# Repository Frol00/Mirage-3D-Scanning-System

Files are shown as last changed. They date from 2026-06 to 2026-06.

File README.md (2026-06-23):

# Mirage 3D Scanning System

**Mirage 3D Scanning System** is an open-source RGB-D 3D scanning platform based on Raspberry Pi CM5, Intel RealSense D415, and a custom Mirage V1.1 expansion board.

The system is designed for RGB-D data acquisition, wireless or USB-based data transfer, and 3D reconstruction using a modified InfiniTAM-based MirageApp pipeline.

Repository: https://github.com/Frol00/Mirage-3D-Scanning-System

## Architecture

The system has a distributed architecture and consists of two main nodes:

### Data Acquisition Node
Built on a Raspberry Pi CM5, a Mirage V1.1 expansion board and an Intel RealSense D415 RGB-D camera. Used to connect the camera, launch the local interface, display the system status, control operating modes and transmit the RGB-D stream to a PC. Features physical control buttons to start, stop or reset the scanning process. Designed to operate on battery power.

### Computing Node
Implemented on a PC. Runs MirageApp, a modified program based on InfiniTAM, which receives RGB-D data, processes the depth map, tracks the camera position, integrates frames into a TSDF representation and constructs a polygonal 3D model. The result can be saved in OBJ format.

## Operating Modes

- **Network mode** — the Intel RealSense D415 is connected to the data acquisition node and the RGB-D stream is transmitted to the PC via Wi-Fi.
- **USB mode** — the Intel RealSense D415 is connected directly to the PC via USB.

## Repository Structure

```
hardware/...      — schematics, PCB files and enclosure models
software/...      — software for the data acquisition node and data processing node
experiments/...   — measurements, test models and experimental results
```

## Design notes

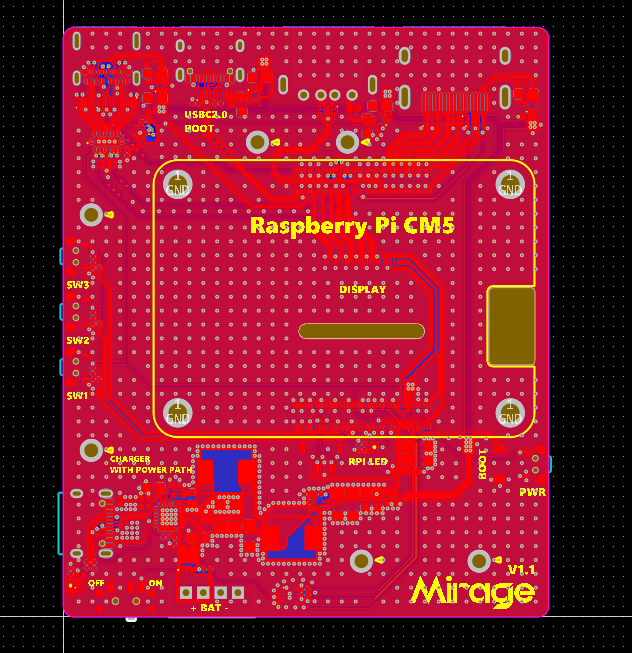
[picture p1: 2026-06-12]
hardware/pcb/PCB_TOP.png

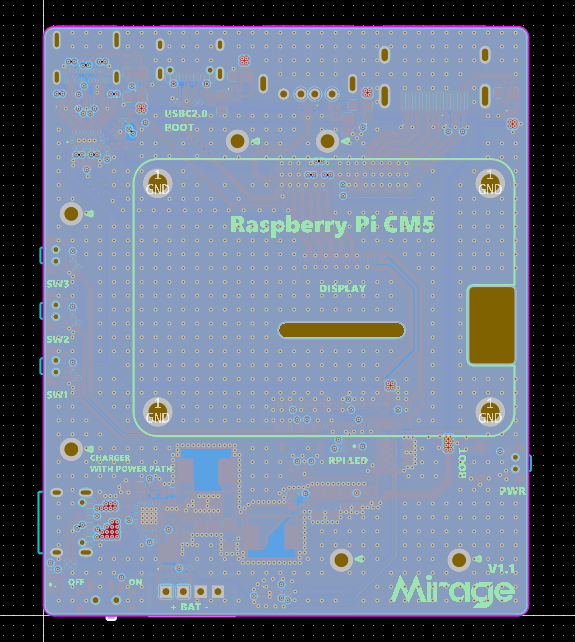
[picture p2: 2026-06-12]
hardware/pcb/PCB_INNER2.png

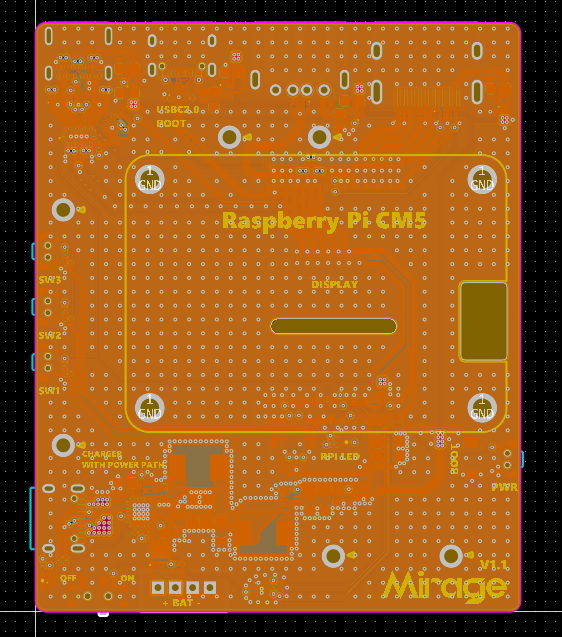
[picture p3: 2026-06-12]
hardware/pcb/PCB_INNER1.png

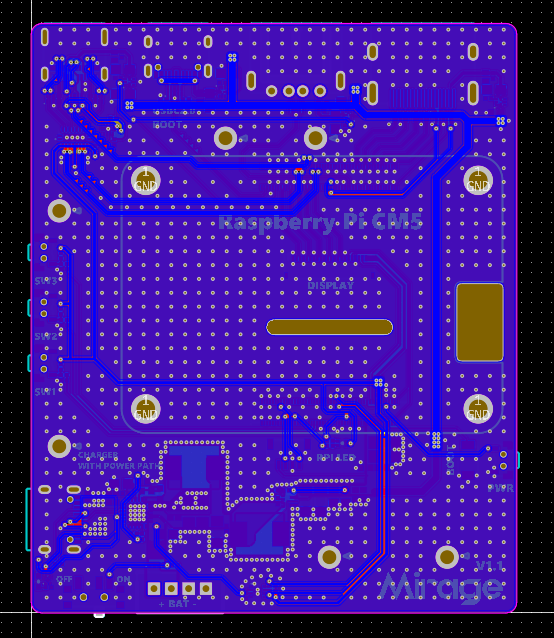
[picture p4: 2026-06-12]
hardware/pcb/PCB_BOTTOM.png

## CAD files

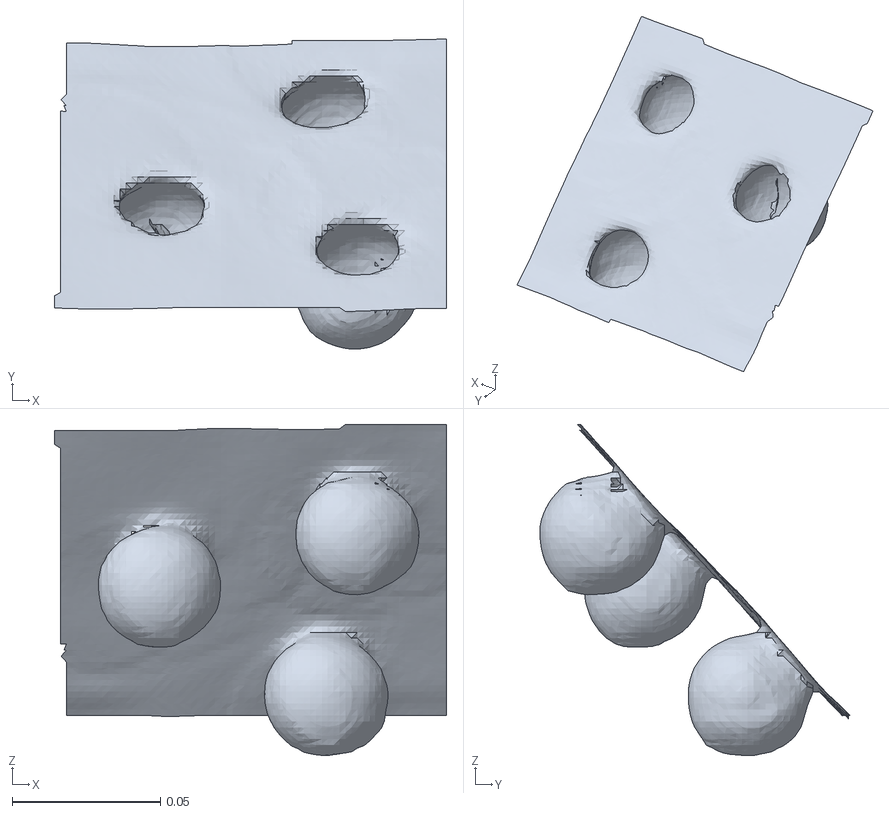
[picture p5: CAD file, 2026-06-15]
experiments/models/Mirage_ball_WIFI.obj
0.132 x 0.104 x 0.112

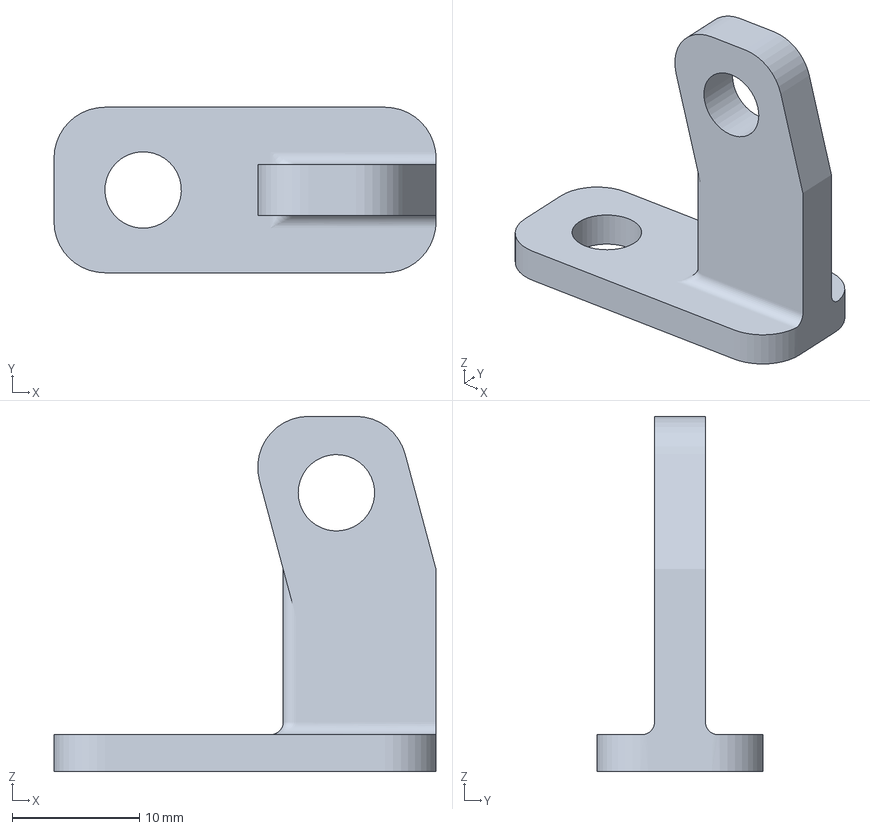
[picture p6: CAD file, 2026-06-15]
hardware/enclosure/CamHolder_TOP.3mf
30.0 x 13.0 x 27.9 mm

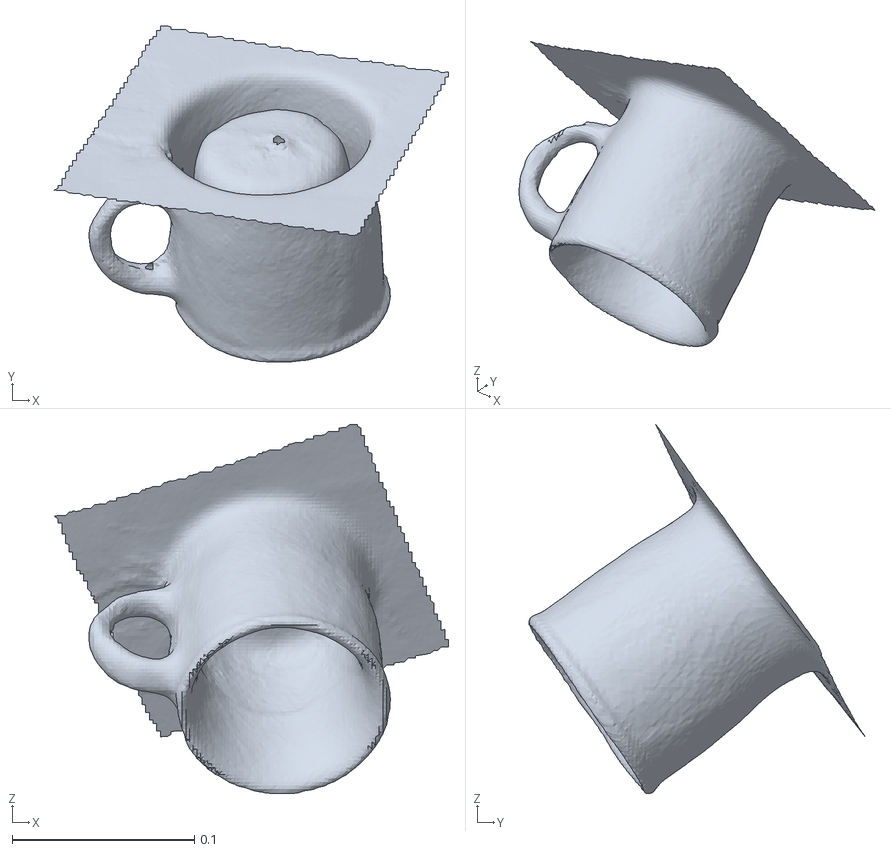
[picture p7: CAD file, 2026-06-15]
experiments/models/Mirage_cup_WIFI.obj
0.216 x 0.184 x 0.202

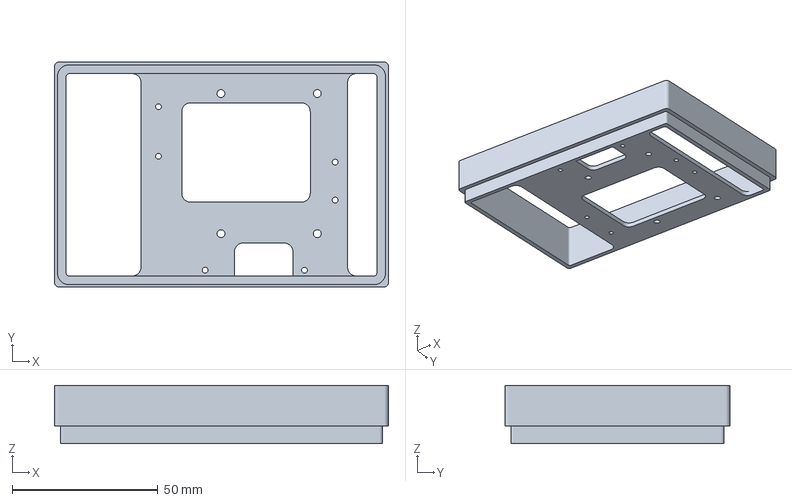
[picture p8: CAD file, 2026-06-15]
hardware/enclosure/BOX_TOP.3mf
114.4 x 77.1 x 20.0 mm

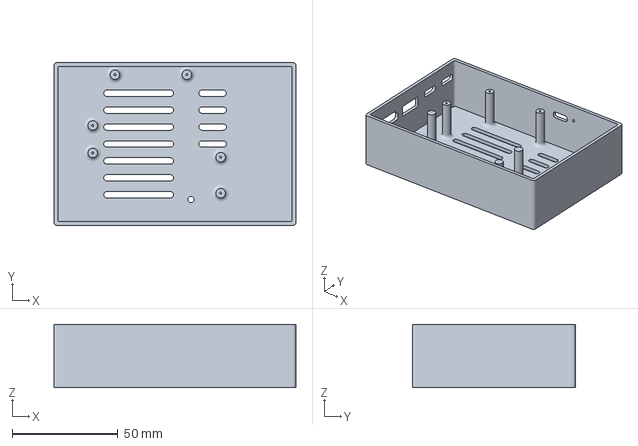
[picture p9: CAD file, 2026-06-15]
hardware/enclosure/BOX_BOTTOM.3mf
114.4 x 77.1 x 30.0 mm

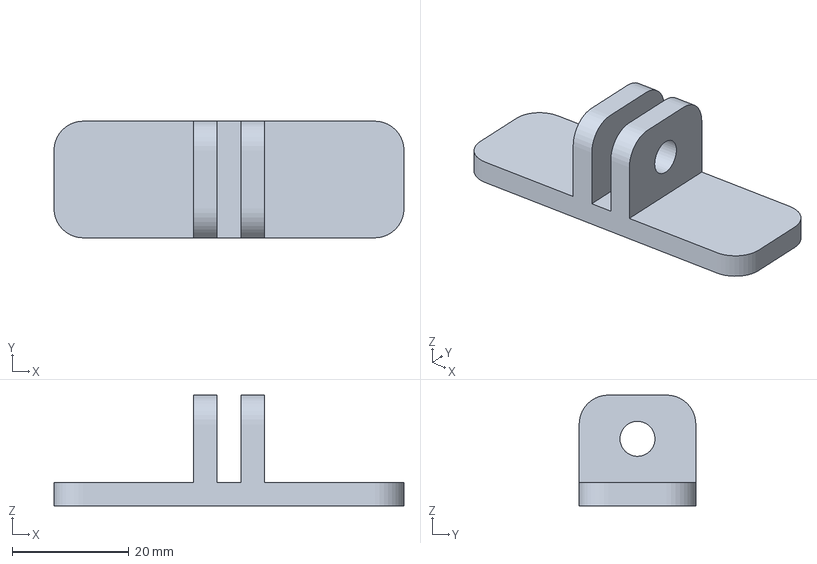
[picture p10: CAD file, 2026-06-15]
hardware/enclosure/CamHolder_BOTTOM.3mf
60.0 x 20.0 x 19.0 mm

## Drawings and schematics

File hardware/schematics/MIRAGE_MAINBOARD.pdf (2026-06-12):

# Raspberry Pi CM5 Pinout

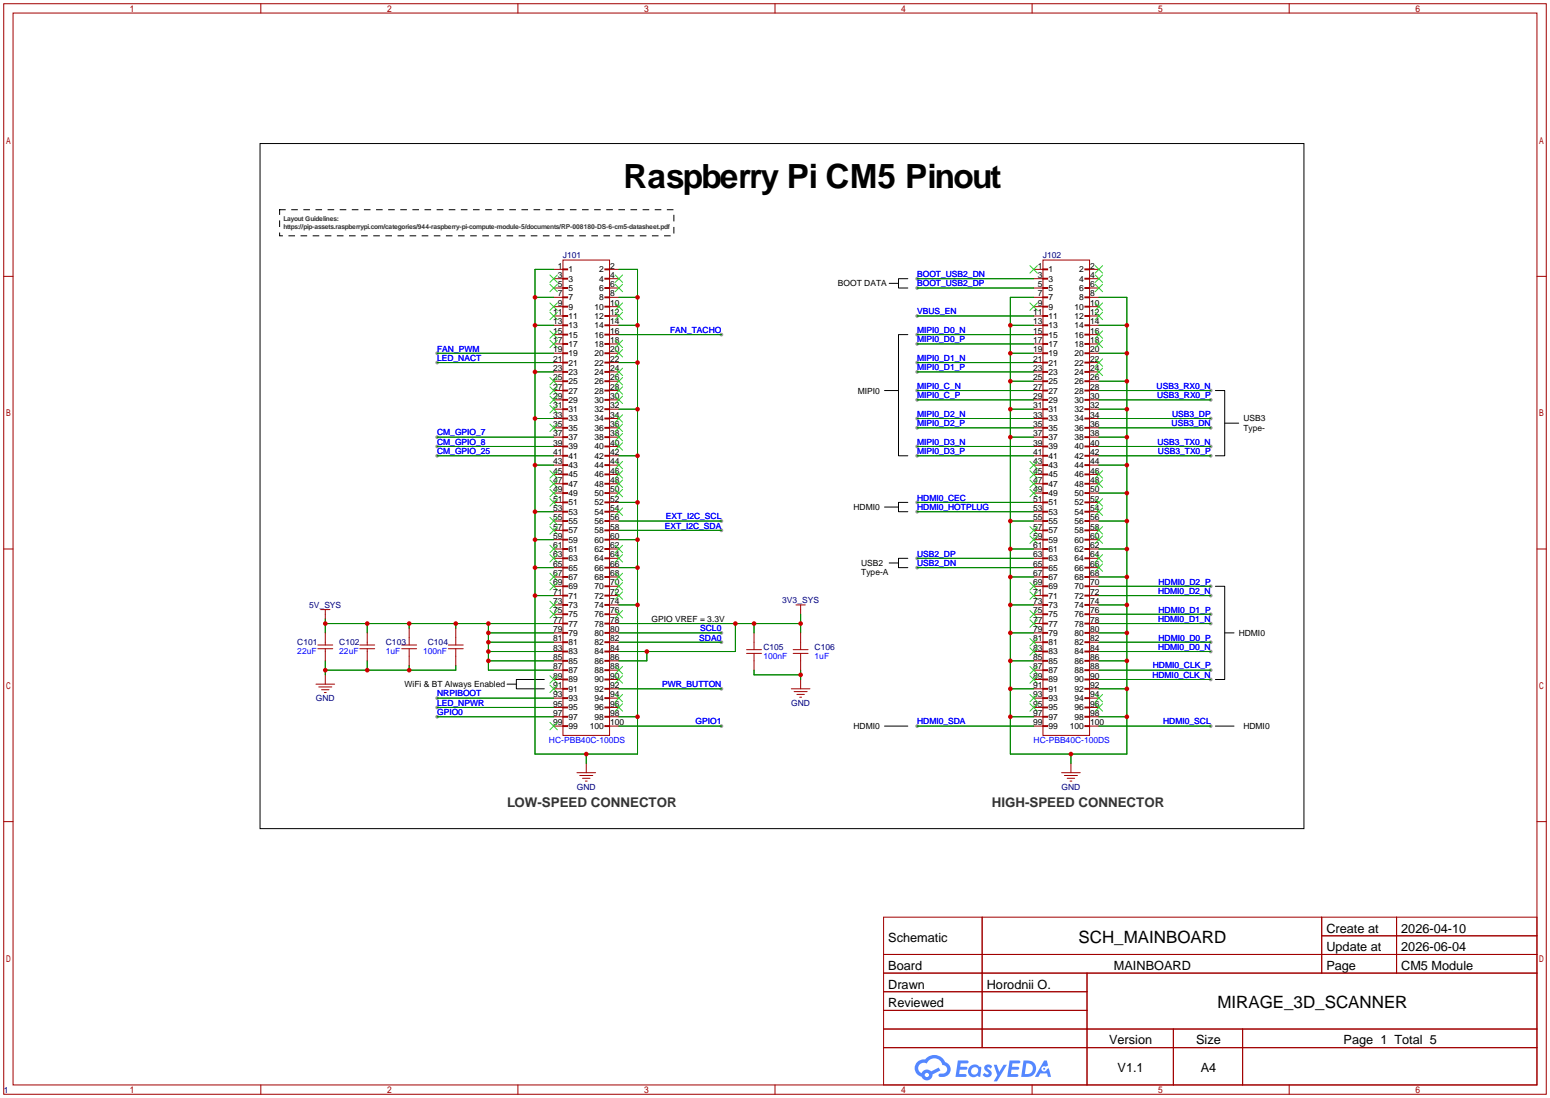
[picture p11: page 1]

Layout Guidelines:
https://pip-assets.raspberrypi.com/categories/944-raspberry-pi-compute-module-5/documents/RP-008180-DS-6-cm5-datasheet.pdf

Schematic | SCH_MAINBOARD | Create at | 2026-04-10

Update at | 2026-06-04

Board | MAINBOARD | Page | CM5 Module
Drawn | Horodnii O. | MIRAGE_3D_SCANNER
Reviewed

Version | Size | Page 1 Total 5
V1.1 | A4

# BATTERY CHARGER WITH POWER PATH

# DC-DC BOOST

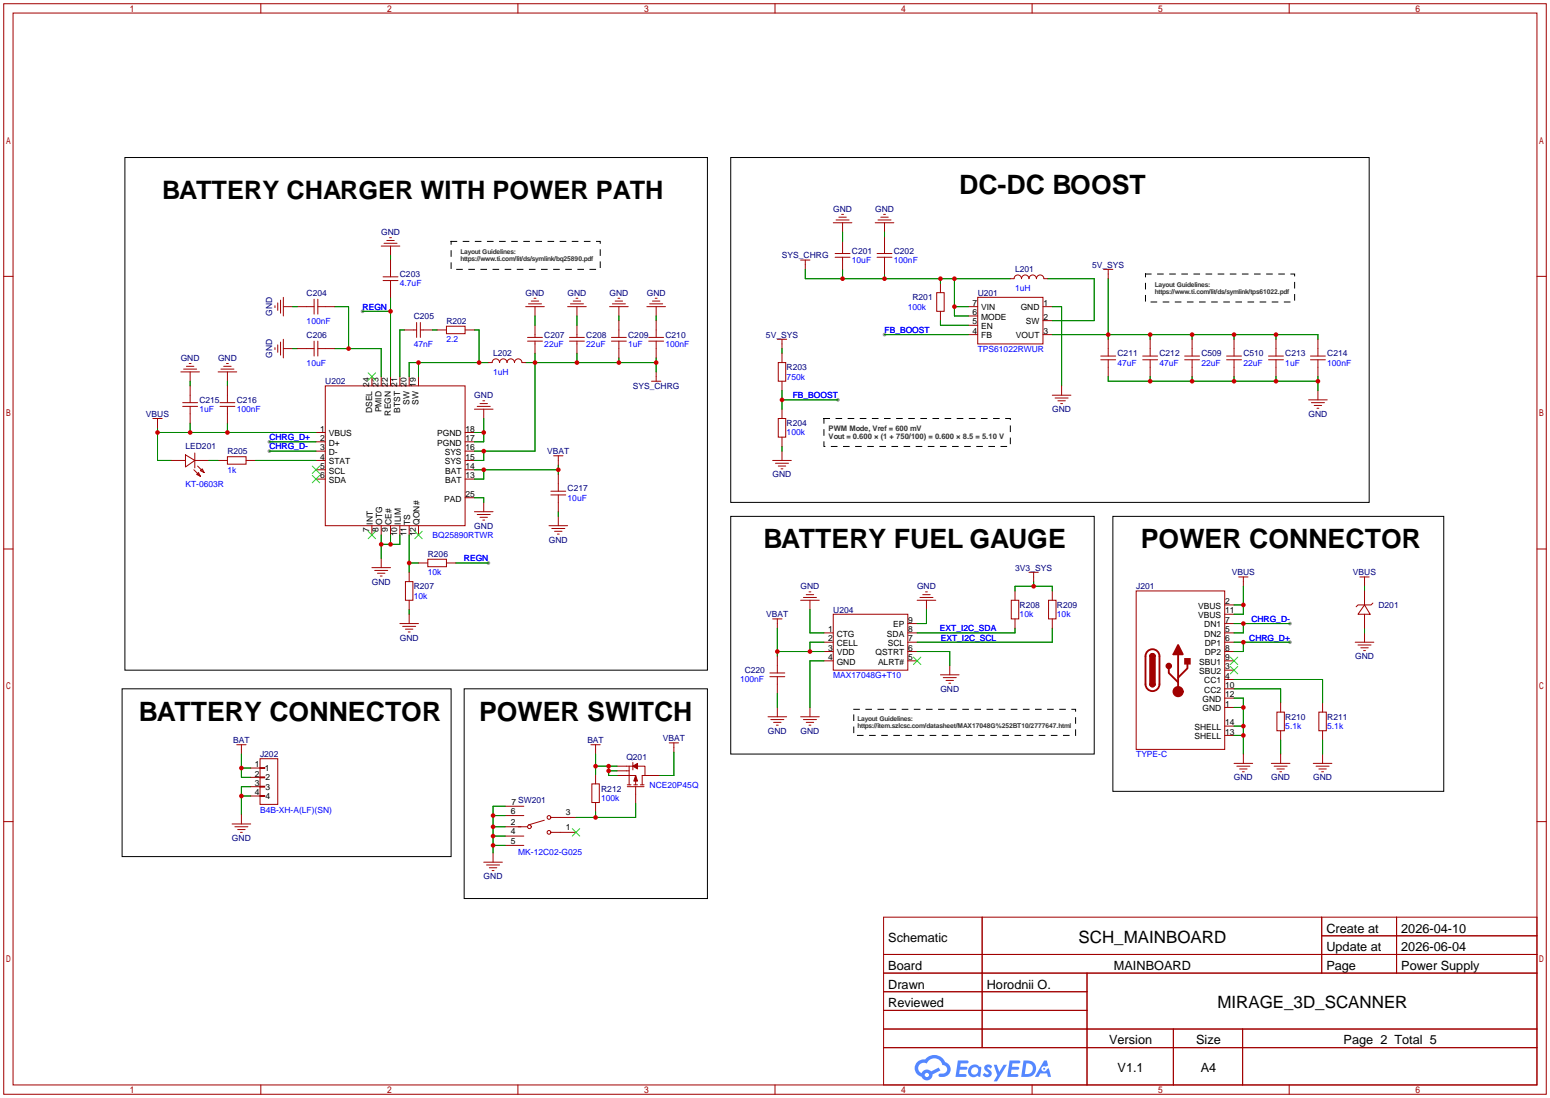
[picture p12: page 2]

Layout Guidelines:
https://www.ti.com/lit/ds/symlink/bq25890.pdf

https://www.ti.com/lit/ds/symlink/tps61022.pdf

BAT 13 BAT 14 SYS 15 SYS 16 PGND 17 PGND 18

PWM Mode, Vref = 600 mV
Vout = 0.600 × (1 + 750/100) = 0.600 × 8.5 = 5.10 V

https://item.szlcsc.com/datasheet/MAX17048G%252BT10/2777647.html

Schematic | SCH_MAINBOARD | Create at | 2026-04-10

Update at | 2026-06-04

Board | MAINBOARD | Page | Power Supply
Drawn | Horodnii O. | MIRAGE_3D_SCANNER
Reviewed

# USB 2.0 Type-A (DEFAULT)

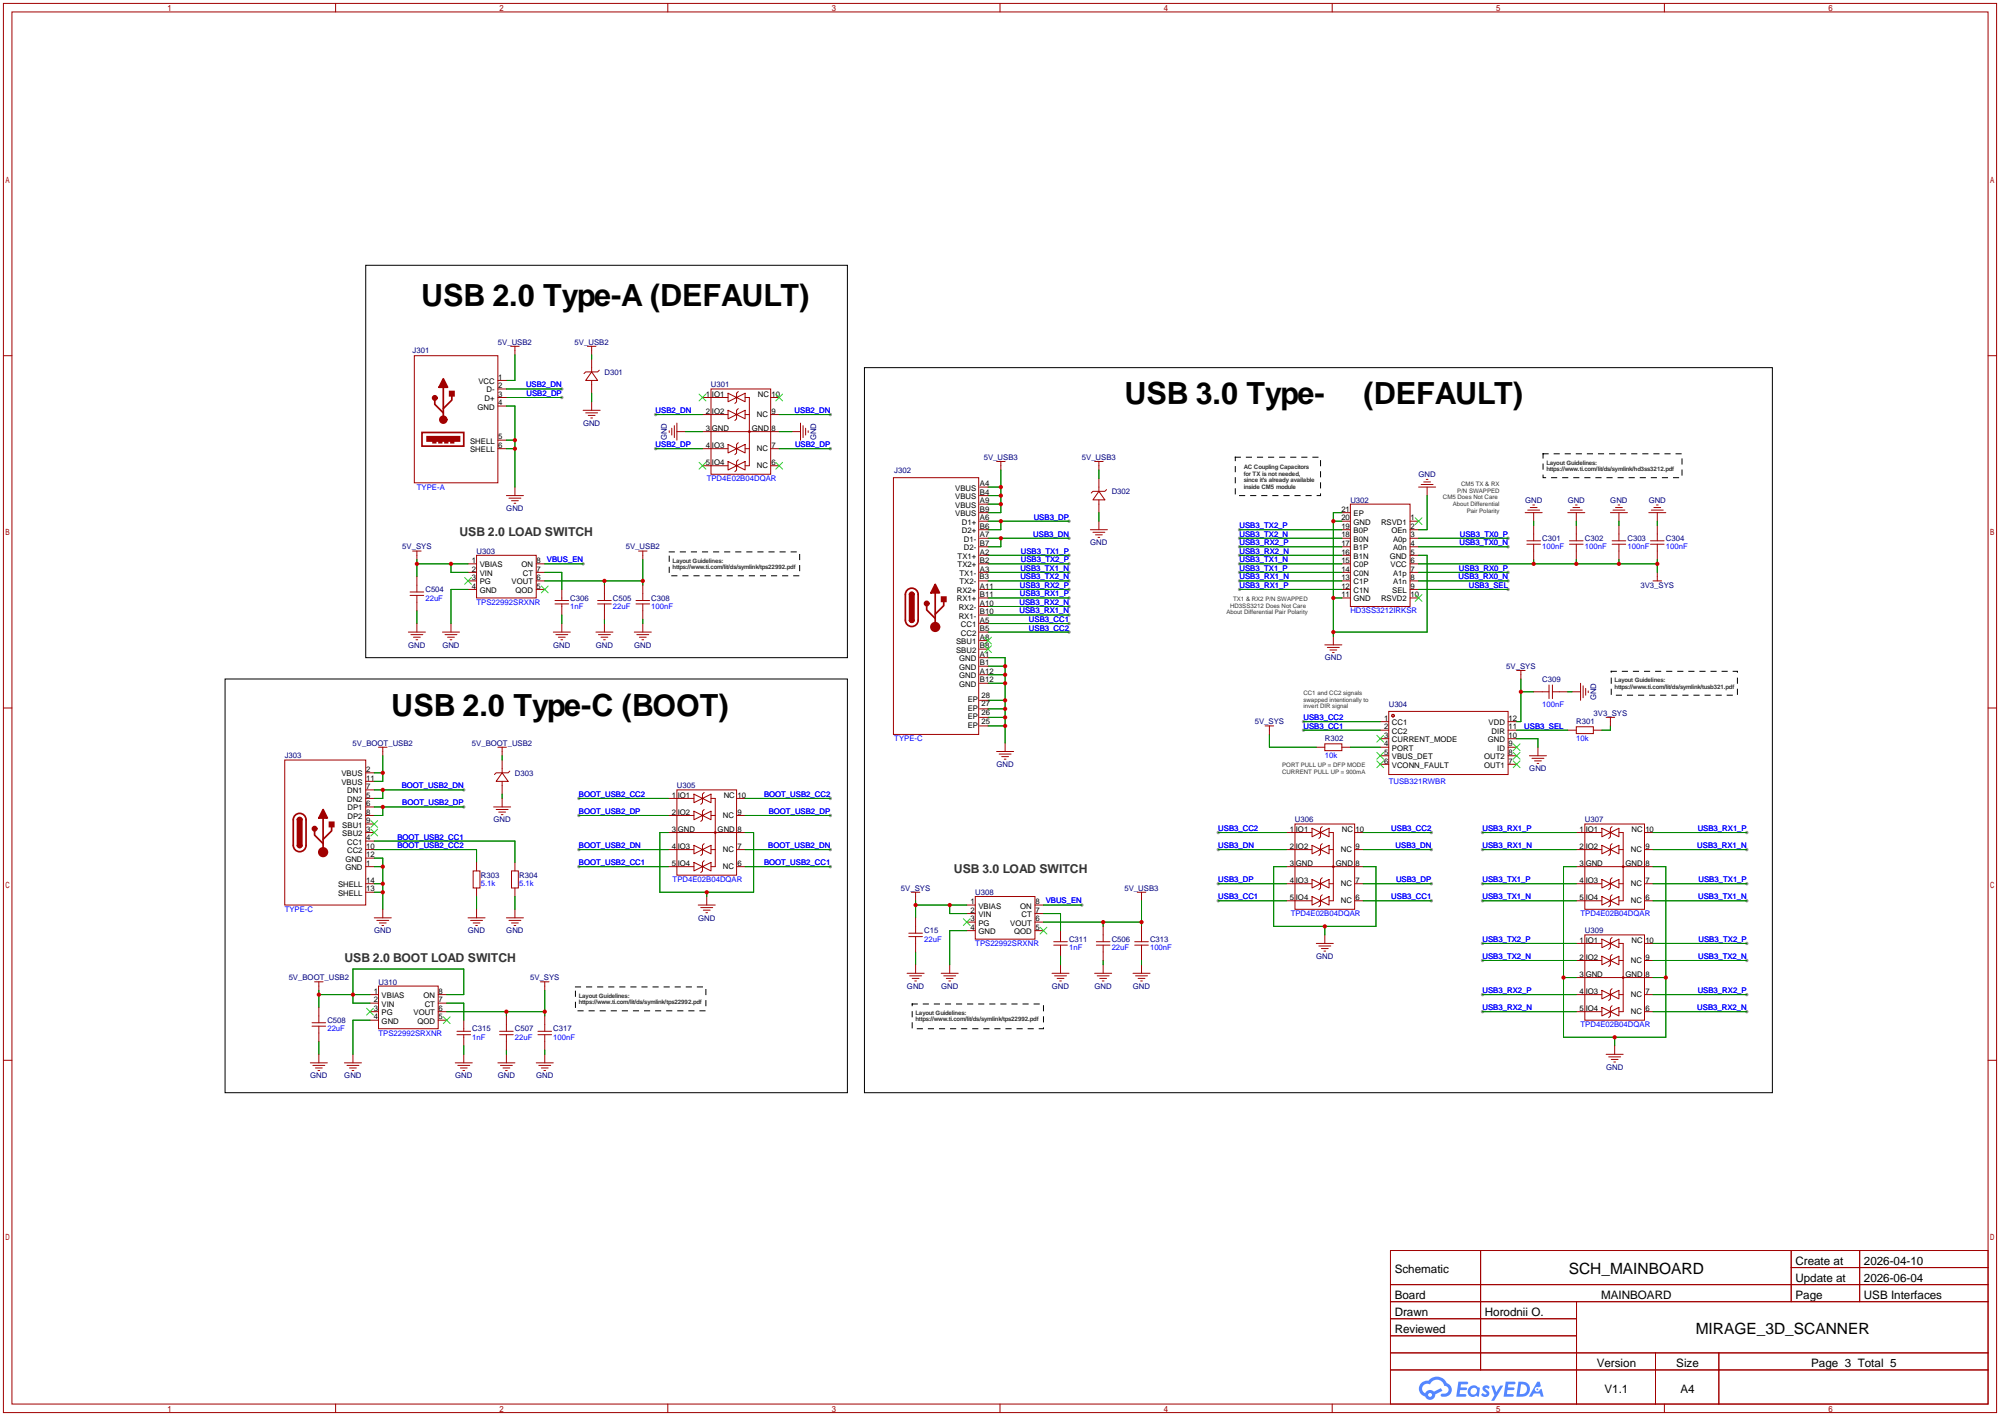
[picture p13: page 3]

Layout Guidelines:
https://www.ti.com/lit/ds/symlink/hd3ss3212.pdf

AC Coupling Capacitors
for TX is not needed,
since it's already available
inside CM5 module

https://www.ti.com/lit/ds/symlink/tps22992.pdf

https://www.ti.com/lit/ds/symlink/tusb321.pdf

PORT PULL UP = DFP MODE
CURRENT PULL UP = 900mA

GND
USB 2.0 BOOT LOAD SWITCH

Schematic | SCH_MAINBOARD | Create at | 2026-04-10

Update at | 2026-06-04

Board | MAINBOARD | Page | USB Interfaces
Drawn | Horodnii O. | MIRAGE_3D_SCANNER
Reviewed

# HDMI-A

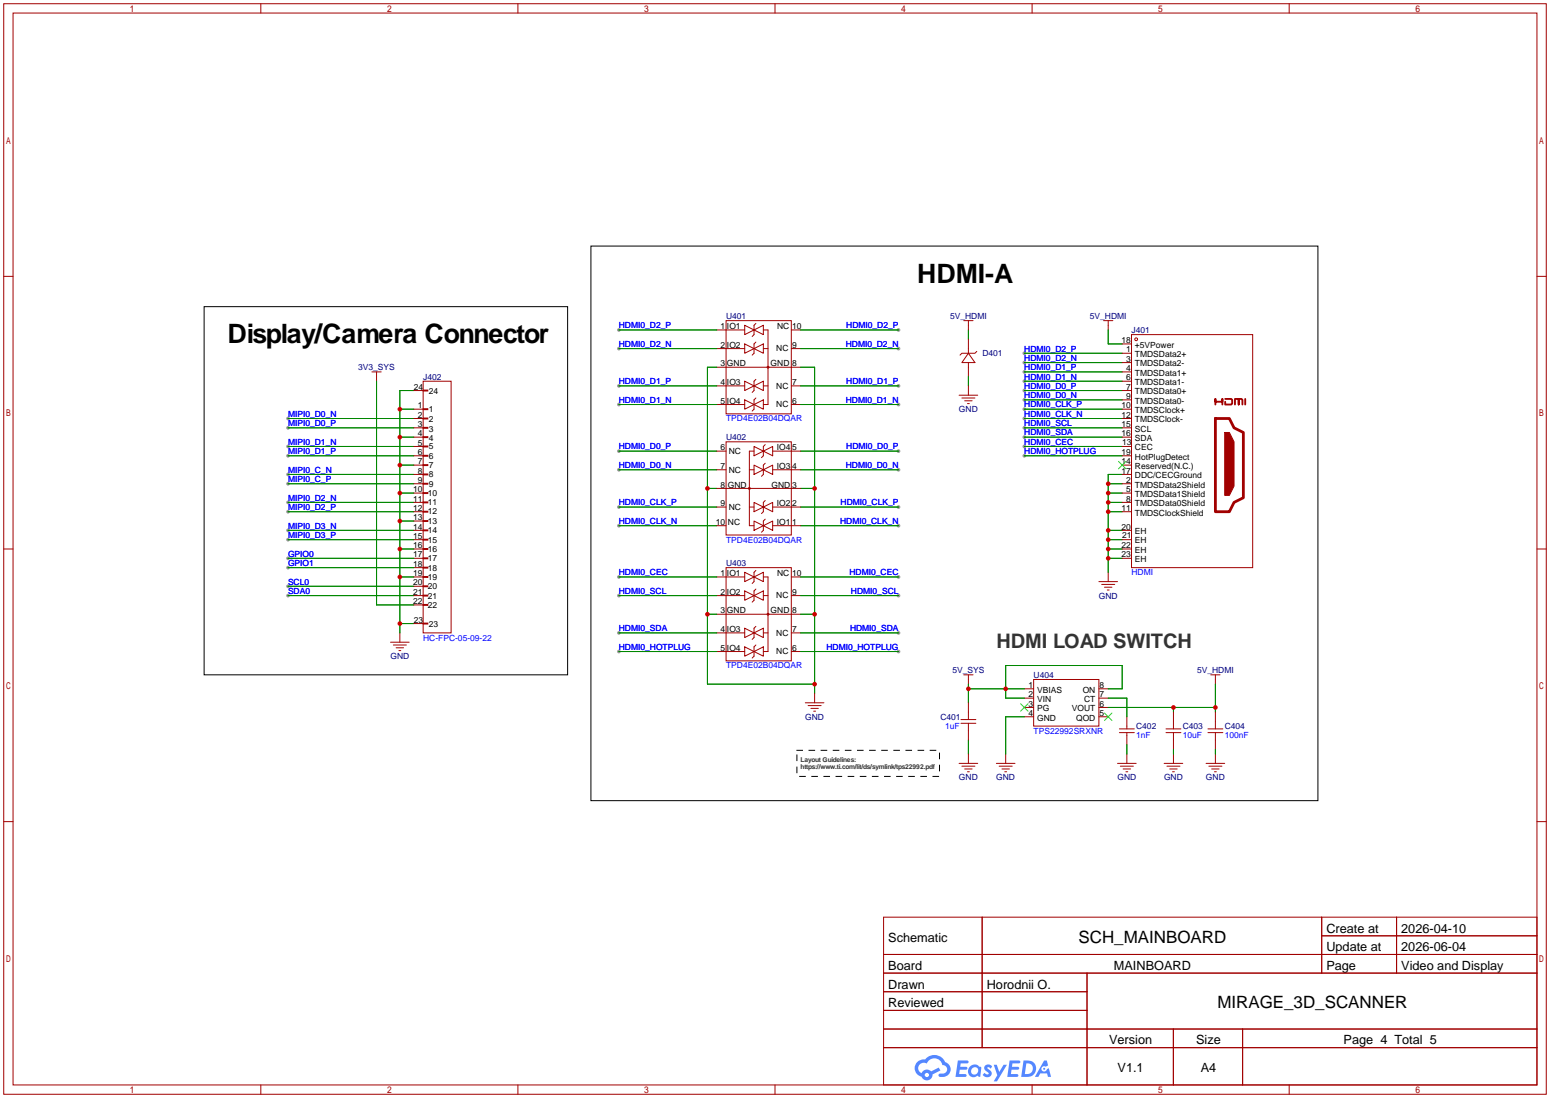
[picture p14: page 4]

Layout Guidelines:
https://www.ti.com/lit/ds/symlink/tps22992.pdf

Schematic | SCH_MAINBOARD | Create at | 2026-04-10

Update at | 2026-06-04

Board | MAINBOARD | Page | Video and Display
Drawn | Horodnii O. | MIRAGE_3D_SCANNER
Reviewed

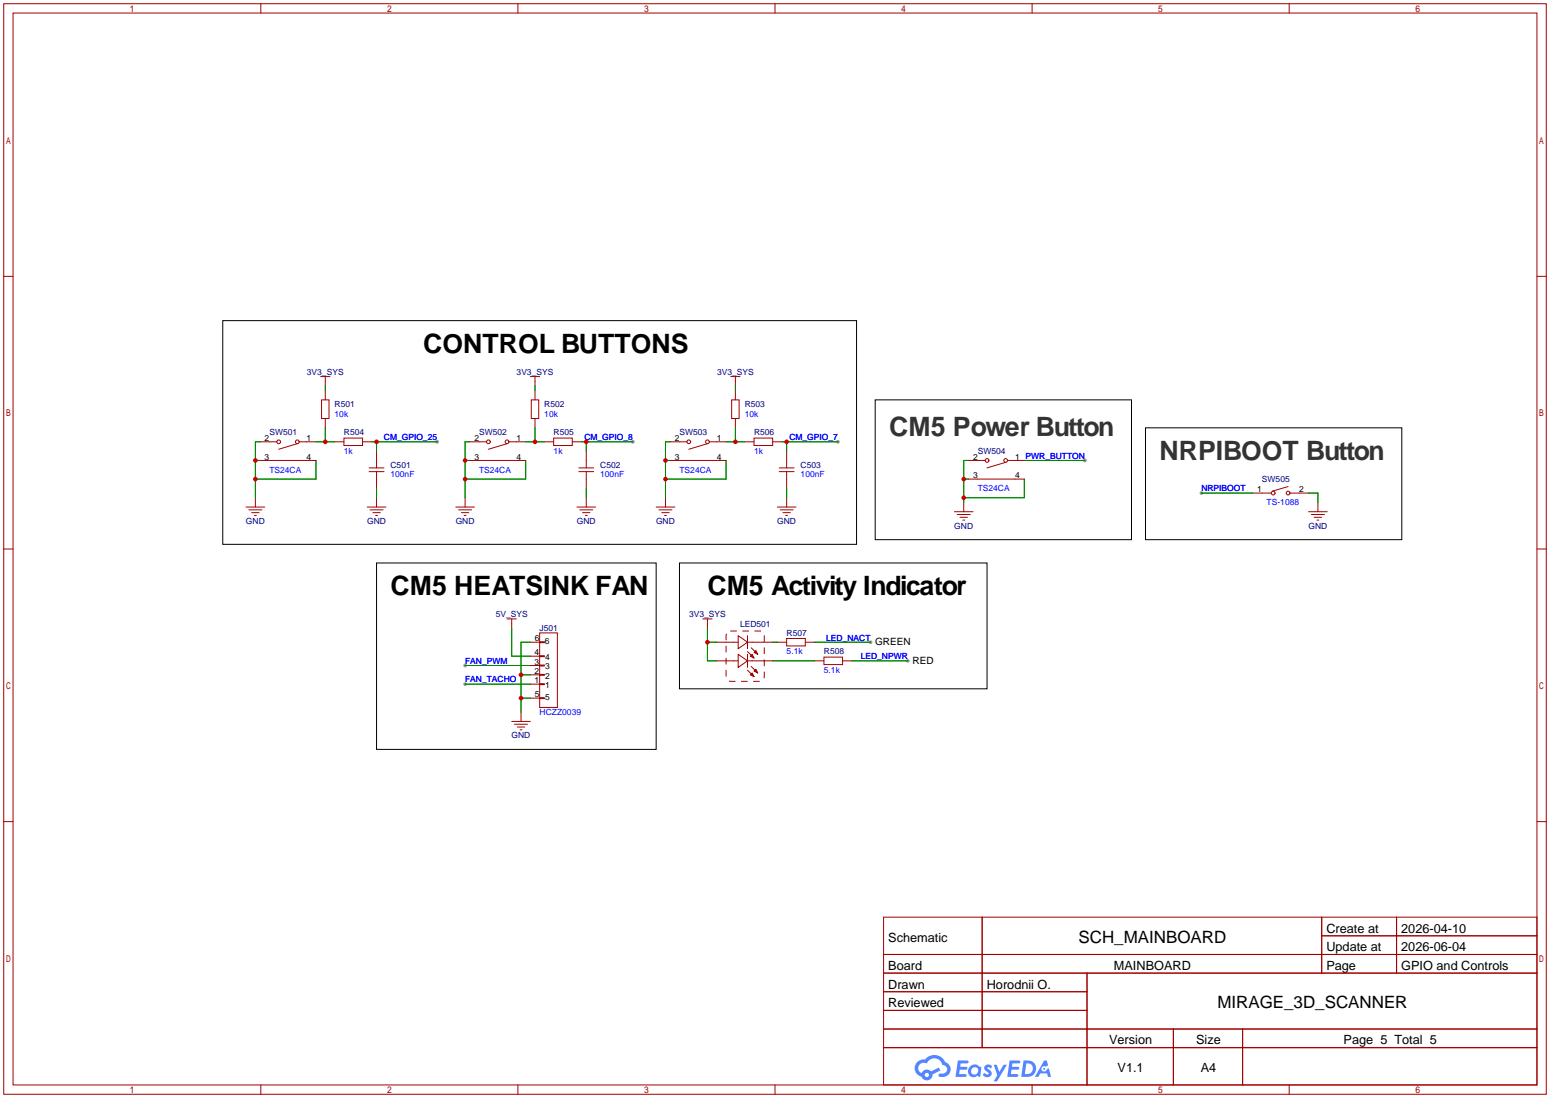
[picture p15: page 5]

Schematic | SCH_MAINBOARD | Create at | 2026-04-10

Update at | 2026-06-04

Board | MAINBOARD | Page | GPIO and Controls
Drawn | Horodnii O. | MIRAGE_3D_SCANNER
Reviewed

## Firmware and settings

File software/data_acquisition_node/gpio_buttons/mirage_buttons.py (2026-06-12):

#!/usr/bin/env python3
import argparse
import json
import os
import signal
import socket
import sys
import threading
import time
import urllib.error
import urllib.parse
import urllib.request
from http.server import ThreadingHTTPServer, BaseHTTPRequestHandler
from pathlib import Path

try:
    from gpiozero import Button
    GPIO_AVAILABLE = True
except Exception as exc:
    Button = None
    GPIO_AVAILABLE = False
    GPIO_IMPORT_ERROR = exc


SCRIPT_DIR = Path(__file__).resolve().parent
DEFAULT_CONFIG = SCRIPT_DIR / "mirage_buttons_config.json"
COMMANDS = {"start", "stop", "reset"}


def log(message):
    print(time.strftime("[%Y-%m-%d %H:%M:%S]"), message, flush=True)


def load_json(path, fallback):
    try:
        return json.loads(Path(path).read_text(encoding="utf-8"))
    except FileNotFoundError:
        return fallback


def write_json(path, data):
    path = Path(path)
    path.parent.mkdir(parents=True, exist_ok=True)
    path.write_text(json.dumps(data, indent=2, ensure_ascii=False), encoding="utf-8")


class ClientState:
    def __init__(self, state_file, default_port, default_protocol):
        self.state_file = Path(state_file)
        self.default_port = int(default_port)
        self.default_protocol = str(default_protocol)
        self.lock = threading.Lock()
        self.client = self._load()

    def _load(self):
        data = load_json(self.state_file, {})
        if not isinstance(data, dict):
            return {}
        return data

    def get(self):
        with self.lock:
            return dict(self.client)

    def clear(self):
        with self.lock:
            self.client = {}
            write_json(self.state_file, self.client)

    def register(self, ip, port=None, protocol=None):
        if not port:
            port = self.default_port
        if not protocol:
            protocol = self.default_protocol

        client = {
            "ip": str(ip),
            "port": int(port),
            "protocol": str(protocol).lower(),
            "registered_at": time.time()
        }

        with self.lock:
            self.client = client
            write_json(self.state_file, self.client)

        return client


class MirageButtons:
    def __init__(self, config):
        self.config = config
        client_cfg = config.get("client", {})
        self.client_state = ClientState(
            config.get("state_file", "/home/frol/mirage_buttons/client_state.json"),
            client_cfg.get("default_port", 5055),
            client_cfg.get("protocol", "http")
        )
        self.httpd = None
        self.buttons = []
        self.stopping = threading.Event()

    def check_token(self, handler):
        expected = str(self.config.get("token", "") or "")
        if not expected:
            return True

        header = handler.headers.get("X-Mirage-Token", "")
        query = urllib.parse.parse_qs(urllib.parse.urlparse(handler.path).query)
        query_token = query.get("token", [""])[0]
        return header == expected or query_token == expected

    def send_command(self, command):
        command = str(command).strip().lower()
        if command not in COMMANDS:
            raise ValueError("Unknown command: " + command)

        client = self.client_state.get()
        if not client.get("ip"):
            log("Button command ignored, no active PC client: " + command)
            return {"ok": False, "error": "No active client", "command": command}

        protocol = client.get("protocol", "http")
        if protocol == "udp":
            return self._send_udp(client, command)
        return self._send_http(client, command)

    def _send_http(self, client, command):
        cfg = self.config.get("client", {})
        template = cfg.get("http_path_template", "/{command}")
        method = str(cfg.get("http_method", "GET")).upper()
        timeout = float(cfg.get("timeout_sec", 1.0))
        path = template.format(command=urllib.parse.quote(command))
        if not path.startswith("/"):
            path = "/" + path

        url = "http://{}:{}{}".format(client["ip"], int(client["port"]), path)
        data = None
        headers = {}

        token = str(self.config.get("token", "") or "")
        if token:
            headers["X-Mirage-Token"] = token

        if method == "POST":
            data = json.dumps({"command": command}).encode("utf-8")
            headers["Content-Type"] = "application/json"

        req = urllib.request.Request(url, data=data, headers=headers, method=method)

        try:
            with urllib.request.urlopen(req, timeout=timeout) as response:
                body = response.read(256).decode("utf-8", errors="replace")
            log("Sent {} to {} by HTTP {}".format(command, client["ip"], response.status))
            return {"ok": True, "command": command, "url": url, "status": response.status, "body": body}
        except urllib.error.URLError as exc:
            log("Failed to send {} to {}: {}".format(command, client["ip"], exc))
            return {"ok": False, "command": command, "url": url, "error": str(exc)}

    def _send_udp(self, client, command):
        cfg = self.config.get("client", {})
        timeout = float(cfg.get("timeout_sec", 1.0))
        encoding = cfg.get("udp_encoding", "utf-8")
        payload = command.encode(encoding)

        with socket.socket(socket.AF_INET, socket.SOCK_DGRAM) as sock:
            sock.settimeout(timeout)
            sock.sendto(payload, (client["ip"], int(client["port"])))

        log("Sent {} to {} by UDP".format(command, client["ip"]))
        return {"ok": True, "command": command}

    def start_http_server(self):
        app = self

        class Handler(BaseHTTPRequestHandler):
            server_version = "MirageButtons/1.0"

            def log_message(self, fmt, *args):
                log("{} {}".format(self.client_address[0], fmt % args))

            def _json(self, data, code=200):
                body = json.dumps(data, ensure_ascii=False).encode("utf-8")
                self.send_response(code)
                self.send_header("Content-Type", "application/json; charset=utf-8")
                self.send_header("Content-Length", str(len(body)))
                self.send_header("Cache-Control", "no-store")
                self.end_headers()
                self.wfile.write(body)

            def _body_json(self):
                length = int(self.headers.get("Content-Length", "0") or "0")
                if length <= 0:
                    return {}
                raw = self.rfile.read(length)
                try:
                    return json.loads(raw.decode("utf-8"))
                except Exception:
                    return {}

            def _require_token(self):
                if app.check_token(self):
                    return True
                self._json({"ok": False, "error": "Forbidden"}, 403)
                return False

            def do_GET(self):
                if not self._require_token():
                    return

                path = urllib.parse.urlparse(self.path).path
                if path == "/status":
                    return self._json({
                        "ok": True,
                        "client": app.client_state.get(),
                        "gpio_available": GPIO_AVAILABLE
                    })

                if path == "/clear":
                    app.client_state.clear()
                    return self._json({"ok": True})

                if path.startswith("/send/"):
                    command = path.rsplit("/", 1)[-1]
                    return self._json(app.send_command(command))

                return self._json({"ok": False, "error": "Not found"}, 404)

            def do_POST(self):
                if not self._require_token():
                    return

                path = urllib.parse.urlparse(self.path).path
                data = self._body_json()

                if path == "/register":
                    client = app.client_state.register(
                        self.client_address[0],
                        data.get("port"),
                        data.get("protocol")
                    )
                    log("Registered active PC client: {}:{} {}".format(
                        client["ip"], client["port"], client["protocol"]))
                    return self._json({"ok": True, "client": client})

                if path == "/clear":
                    app.client_state.clear()
                    return self._json({"ok": True})

                if path.startswith("/send/"):
                    command = path.rsplit("/", 1)[-1]
                    return self._json(app.send_command(command))

                return self._json({"ok": False, "error": "Not found"}, 404)

        host = self.config.get("listen_host", "0.0.0.0")
        port = int(self.config.get("listen_port", 8091))
        self.httpd = ThreadingHTTPServer((host, port), Handler)

        thread = threading.Thread(target=self.httpd.serve_forever, daemon=True)
        thread.start()
        log("Mirage buttons server listening on {}:{}".format(host, port))

    def setup_buttons(self):
        if not GPIO_AVAILABLE:
            log("GPIO unavailable: {}".format(GPIO_IMPORT_ERROR))
            log("HTTP registration/test server will still run.")
            return

        button_cfg = self.config.get("buttons", {})

        self._add_press_button("start", button_cfg.get("start", {}))
        self._add_press_button("stop", button_cfg.get("stop", {}))
        self._add_reset_button(button_cfg.get("reset", {}))

    def _add_press_button(self, command, cfg):
        pin = cfg.get("pin")
        if pin is None:
            log("Button disabled, no pin configured: " + command)
            return

        btn = Button(
            int(pin),
            pull_up=bool(cfg.get("pull_up", True)),
            bounce_time=float(cfg.get("bounce_time", 0.08))
        )
        btn.when_pressed = lambda cmd=command: self.send_command(cmd)
        self.buttons.append(btn)
        log("GPIO button {} on BCM pin {}".format(command, pin))

    def _add_reset_button(self, cfg):
        pin = cfg.get("pin")
        if pin is None:
            log("Reset button disabled, no pin configured.")
            return

        btn = Button(
            int(pin),
            pull_up=bool(cfg.get("pull_up", True)),
            bounce_time=float(cfg.get("bounce_time", 0.08)),
            hold_time=float(cfg.get("hold_time", 1.5)),
            hold_repeat=False
        )
        btn.when_held = lambda: self.send_command("reset")
        self.buttons.append(btn)
        log("GPIO button reset on BCM pin {} hold {} sec".format(pin, btn.hold_time))

    def run(self):
        self.start_http_server()
        self.setup_buttons()

        while not self.stopping.is_set():
            time.sleep(0.25)

    def stop(self):
        self.stopping.set()
        if self.httpd:
            self.httpd.shutdown()


def main():
    parser = argparse.ArgumentParser(description="Mirage GPIO buttons to PC control bridge")
    parser.add_argument("--config", default=str(DEFAULT_CONFIG))
    args = parser.parse_args()

    config = load_json(args.config, {})
    if not config:
        print("Config not found or empty: {}".format(args.config), file=sys.stderr)
        return 2

    app = MirageButtons(config)

    def handle_signal(signum, frame):
        log("Stopping")
        app.stop()

    signal.signal(signal.SIGTERM, handle_signal)
    signal.signal(signal.SIGINT, handle_signal)

    app.run()
    return 0


if __name__ == "__main__":
    raise SystemExit(main())

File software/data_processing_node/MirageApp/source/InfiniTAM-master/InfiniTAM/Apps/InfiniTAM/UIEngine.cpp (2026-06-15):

// Copyright 2014-2017 Oxford University Innovation Limited and the authors of InfiniTAM

#ifdef _WIN32
#ifndef WIN32_LEAN_AND_MEAN
#define WIN32_LEAN_AND_MEAN
#endif
#ifndef NOMINMAX
#define NOMINMAX
#endif
#include <winsock2.h>
#include <ws2tcpip.h>
#ifdef _MSC_VER
#pragma comment(lib, "Ws2_32.lib")
#endif
#endif

#include "UIEngine.h"
#include "ImGuiGlutBridge.h"

#include <algorithm>
#include <cctype>
#include <chrono>
#include <cmath>
#include <iostream>
#include <string.h>
#include <ctime>
#include <sstream>
#include <stdexcept>
#include <thread>

#ifdef __APPLE__
#include <GLUT/glut.h>
#else
#include <GL/glut.h>
#endif

#include <imgui.h>
#include <imgui_impl_opengl3.h>

#ifdef FREEGLUT
#include <GL/freeglut.h>
#else
#if (!defined USING_CMAKE) && (defined _MSC_VER)
#pragma comment(lib, "glut64")
#endif
#endif

#include "../../ITMLib/ITMLibDefines.h"
#include "../../ITMLib/Core/ITMBasicEngine.h"
#include "../../ITMLib/Core/ITMBasicSurfelEngine.h"
#include "../../ITMLib/Core/ITMMultiEngine.h"

#include "../../ORUtils/FileUtils.h"
#include "../../InputSource/FFMPEGWriter.h"
#include "../../InputSource/RealSense2Engine.h"
#include "../../InputSource/RealSense2NetworkEngine.h"

#ifdef COMPILE_WITH_RealSense2
#include <librealsense2/rs.hpp>
#endif

using namespace InfiniTAM::Engine;
using namespace InputSource;
using namespace ITMLib;

UIEngine* UIEngine::instance;

static void safe_glutBitmapString(void *font, const char *str)
{
	size_t len = strlen(str);
	for (size_t x = 0; x < len; ++x) {
		glutBitmapCharacter(font, str[x]);
	}
}

namespace
{
	const char *kResolutionNames[] = { "1280 x 720", "848 x 480", "640 x 480" };
	const Vector2i kResolutions[] = { Vector2i(1280, 720), Vector2i(848, 480), Vector2i(640, 480) };
	const char *kPresetNames[] = { "Default", "High Density", "High Accuracy" };
	const char *kFrameStrideNames[] = { "Every frame", "Every 2nd frame", "Every 3rd frame", "Every 4th frame" };
	const int kFrameStrides[] = { 1, 2, 3, 4 };
	const char *kScanAreaNames[] = { "10 x 10 cm", "25 x 25 cm", "50 x 50 cm", "100 x 100 cm" };
	const float kScanAreaSizesM[] = { 0.10f, 0.25f, 0.50f, 1.00f };
	const char *kMeshDetailNames[] = { "Balanced (5 mm)", "Fine (3 mm)", "Ultra (2 mm)" };
	const float kMeshVoxelSizesM[] = { 0.005f, 0.003f, 0.002f };
	const char *kDepthOnlyTrackerConfig =
		"type=extended,levels=rrbb,useDepth=1,minstep=1e-4,"
		"outlierSpaceC=0.1,outlierSpaceF=0.004,"
		"numiterC=20,numiterF=50,tukeyCutOff=8,"
		"framesToSkip=20,framesToWeight=50,failureDec=20.0";
	const char *kColourDepthTrackerConfig =
		"type=extended,levels=bbb,useDepth=1,useColour=1,"
		"colourWeight=0.2,minstep=1e-4,"
		"outlierColourC=0.175,outlierColourF=0.005,"
		"outlierSpaceC=0.1,outlierSpaceF=0.004,"
		"numiterC=8,numiterF=12,tukeyCutOff=8,"
		"framesToSkip=20,framesToWeight=50,failureDec=20.0";
	const int kRemoteControlDefaultPort = 5055;
	const int kRaspberryButtonControlPort = 8091;

	std::string TrimCopy(const std::string& value)
	{
		size_t begin = 0;
		while (begin < value.size() && std::isspace(static_cast<unsigned char>(value[begin]))) ++begin;

		size_t end = value.size();
		while (end > begin && std::isspace(static_cast<unsigned char>(value[end - 1]))) --end;

		return value.substr(begin, end - begin);
	}

	std::string ExtractHostFromNetworkAddress(const char *address)
	{
		std::string host = TrimCopy(address != NULL ? address : "");
		const std::string::size_type schemePos = host.find("://");
		if (schemePos != std::string::npos)
			host.erase(0, schemePos + 3);

		const std::string::size_type slashPos = host.find_first_of("/\\");
		if (slashPos != std::string::npos)
			host.erase(slashPos);

		if (host.size() > 2 && host[0] == '[')
		{
			const std::string::size_type endBracket = host.find(']');
			if (endBracket != std::string::npos)
				return host.substr(1, endBracket - 1);
		}

		const std::string::size_type portPos = host.find(':');
		if (portPos != std::string::npos)
			host.erase(portPos);

		return TrimCopy(host);
	}

	std::string ExtractHttpRequestPath(const std::string& request)
	{
		const std::string::size_type lineEnd = request.find('\n');
		std::string requestLine = request.substr(0, lineEnd == std::string::npos ? request.size() : lineEnd);
		if (!requestLine.empty() && requestLine[requestLine.size() - 1] == '\r')
			requestLine.erase(requestLine.size() - 1);

		const std::string::size_type firstSpace = requestLine.find(' ');
		if (firstSpace == std::string::npos) return "";

		const std::string method = requestLine.substr(0, firstSpace);
		if (method != "GET") return "";

		const std::string::size_type secondSpace = requestLine.find(' ', firstSpace + 1);
		if (secondSpace == std::string::npos) return "";

		std::string path = requestLine.substr(firstSpace + 1, secondSpace - firstSpace - 1);
		if (path.find("http://") == 0 || path.find("https://") == 0)
		{
			const std::string::size_type schemePos = path.find("://");
			const std::string::size_type firstSlash = path.find('/', schemePos == std::string::npos ? 0 : schemePos + 3);
			path = firstSlash == std::string::npos ? "/" : path.substr(firstSlash);
		}

		const std::string::size_type queryPos = path.find('?');
		if (queryPos != std::string::npos)
			path.erase(queryPos);

		return path;
	}
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
